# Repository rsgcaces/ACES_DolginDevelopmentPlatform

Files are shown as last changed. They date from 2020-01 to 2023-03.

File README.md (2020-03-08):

# RSGC ACES: Dolgin Development Platform (DDP)
 EAGLE and Fusion 360 Design files relating to the RSGC ACES Dolgin Development Platform

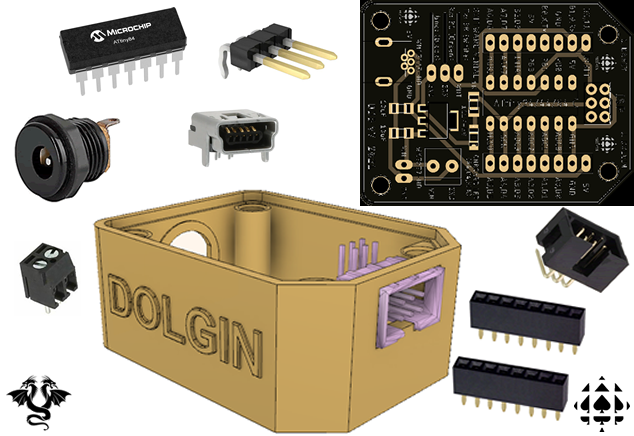
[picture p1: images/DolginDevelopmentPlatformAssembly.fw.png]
DDP Assembly


## USB to TTL Serial Support
Below is an image of the DDP software serial streaming the 2D readings of the thumb joystick to a Processing sketch that dynamically presents the circular trig functions.   
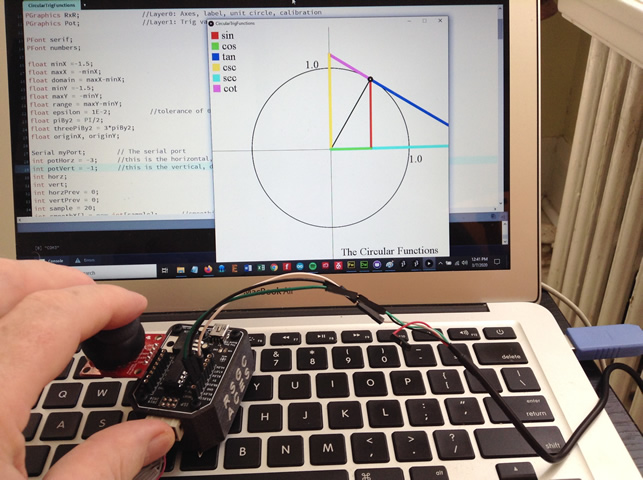
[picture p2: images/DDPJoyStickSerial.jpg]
Serial Support


## Morland Bargraph
The ATtiny84's pins were broken out with specific ACES' devices in mind. The image below shows the Morland Bargraph inserted strategically into the DDP.  
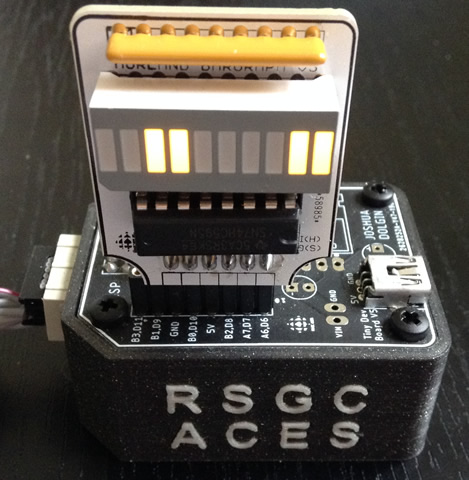
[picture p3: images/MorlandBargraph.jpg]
Morland Bargraph


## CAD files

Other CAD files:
AtTinyV26.f3d

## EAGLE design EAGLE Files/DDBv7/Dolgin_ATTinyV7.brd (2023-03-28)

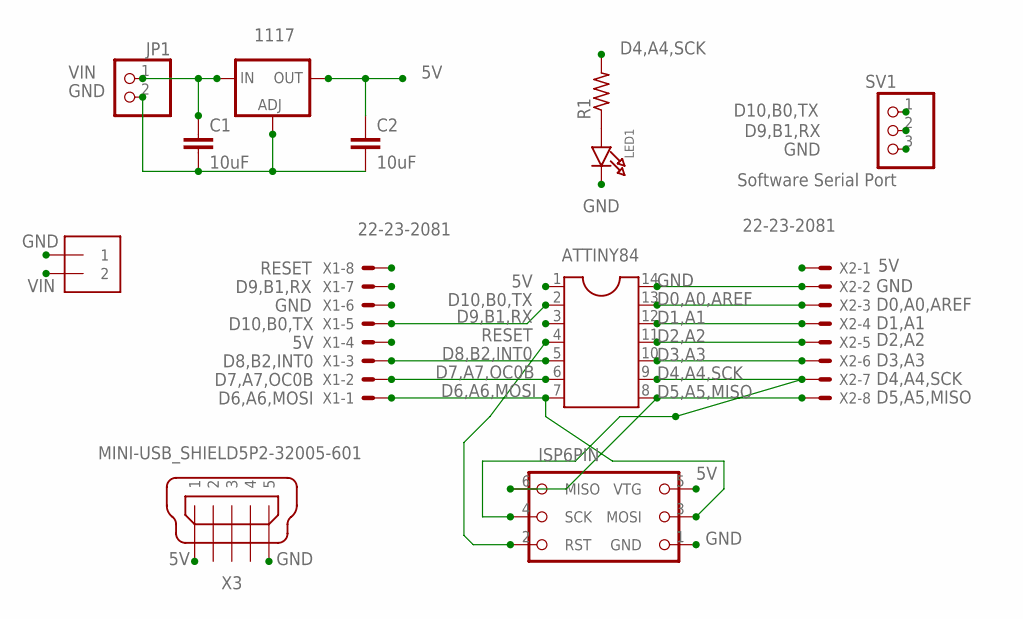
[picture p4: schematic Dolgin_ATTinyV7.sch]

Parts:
1117: LM1117SOT223-REFLOW; SOT223-R
ATTINY84: DIL14
C1, C2: 10uF; 1206
H1: ISP_HEADER; ICSP
J1: 1X2-3.5MM
JP1: PINHD-1X2; 1X02
LED1: LED1206; CHIPLED_1206
R1: R-US_R1206; R1206
SV1: Software Serial Port; 1X03/90
X1, X2: 22-23-2081
X3: MINI-USB_SHIELD5P2-32005-601; 32005-601

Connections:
5V: 1117.2 (OUT), ATTINY84.1, C2.1, H1.5 (VTG), X1.4, X2.1, X3.1
D0,A0,AREF: ATTINY84.13, X2.3
D1,A1: ATTINY84.12, X2.4
D2,A2: ATTINY84.11, X2.5
D3,A3: ATTINY84.10, X2.6
D4,A4,SCK: ATTINY84.9, H1.4 (SCK), R1.2, X2.7
D5,A5,MISO: ATTINY84.8, H1.6 (MISO), X2.8
D6,A6,MOSI: ATTINY84.7, H1.3 (MOSI), X1.1
D7,A7,OC0B: ATTINY84.6, X1.2
D8,B2,INT0: ATTINY84.5, X1.3
D9,B1,RX: ATTINY84.3, SV1.2, X1.7
D10,B0,TX: ATTINY84.2, SV1.3, X1.5
GND: 1117.1 (ADJ), ATTINY84.14, C1.2, C2.2, H1.1 (GND), J1.1, JP1.2, LED1.C, SV1.1, X1.6, X2.2, X3.5
unnamed: LED1.A, R1.1
RESET: ATTINY84.4, H1.2 (RST), X1.8
VIN: 1117.3 (IN), C1.1, J1.2, JP1.1

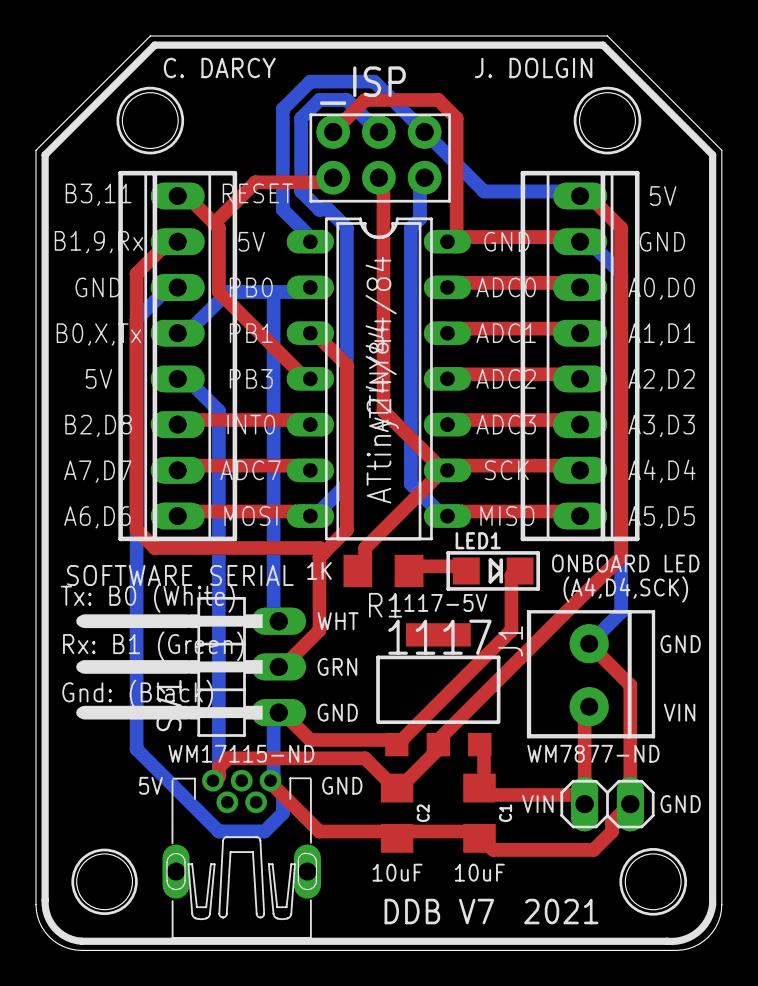
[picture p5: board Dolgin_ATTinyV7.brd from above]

Board: 2 copper layers, 38.1 x 50.8 mm, 17 parts (1 on the bottom side), 16 nets.

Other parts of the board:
U$1, U$2, U$4: ACES_LOGO_SMALL
U$3: MEDIUM_BSILK_TEXT

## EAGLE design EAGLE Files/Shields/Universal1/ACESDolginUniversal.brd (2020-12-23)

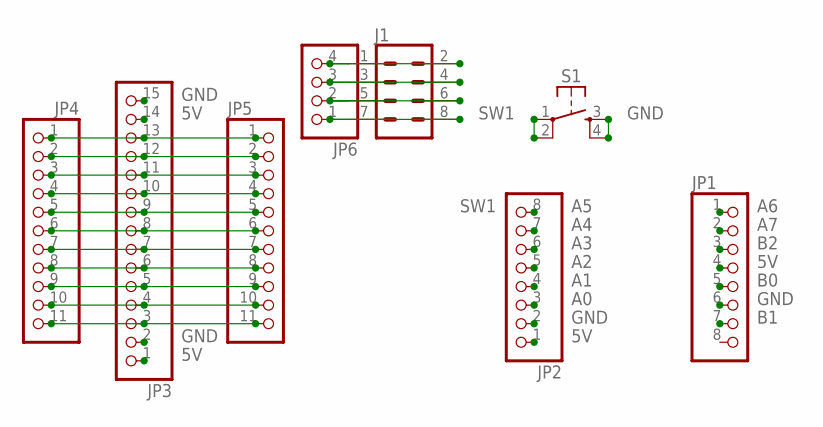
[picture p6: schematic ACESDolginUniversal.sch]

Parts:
J1: CONN_04X2; 2X4
JP1, JP2: PINHD-1X8; 1X08
JP3: PINHD-1X15; 1X15
JP4, JP5: PINHD-1X11; 1X11
JP6: PINHD-1X4; 1X04
S1: MOMENTARY_BUTTONS6MMSMALL; TACTILE_SWITCH_PTH_6.0MM

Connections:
5V: JP1.4, JP2.1, JP3.1, JP3.14
A0: JP2.3
A1: JP2.4
A2: JP2.5
A3: JP2.6
A4: JP2.7
A5: JP2.8
A6: JP1.1
A7: JP1.2
B0: JP1.5
B1: JP1.7
B2: JP1.3
GND: JP1.6, JP2.2, JP3.2, JP3.15, S1.3 (S), S1.4 (S1)
unnamed: J1.1, J1.2, JP6.4
unnamed: J1.3, J1.4, JP6.3
unnamed: J1.5, J1.6, JP6.2
unnamed: JP3.13, JP4.1, JP5.1
unnamed: JP3.12, JP4.2, JP5.2
unnamed: JP3.11, JP4.3, JP5.3
unnamed: JP3.10, JP4.4, JP5.4
unnamed: JP3.9, JP4.5, JP5.5
unnamed: JP3.8, JP4.6, JP5.6
unnamed: JP3.7, JP4.7, JP5.7
unnamed: JP3.6, JP4.8, JP5.8
unnamed: JP3.5, JP4.9, JP5.9
unnamed: JP3.4, JP4.10, JP5.10
unnamed: JP3.3, JP4.11, JP5.11
SW1: J1.7, J1.8, JP6.1, S1.1, S1.2 (P1)

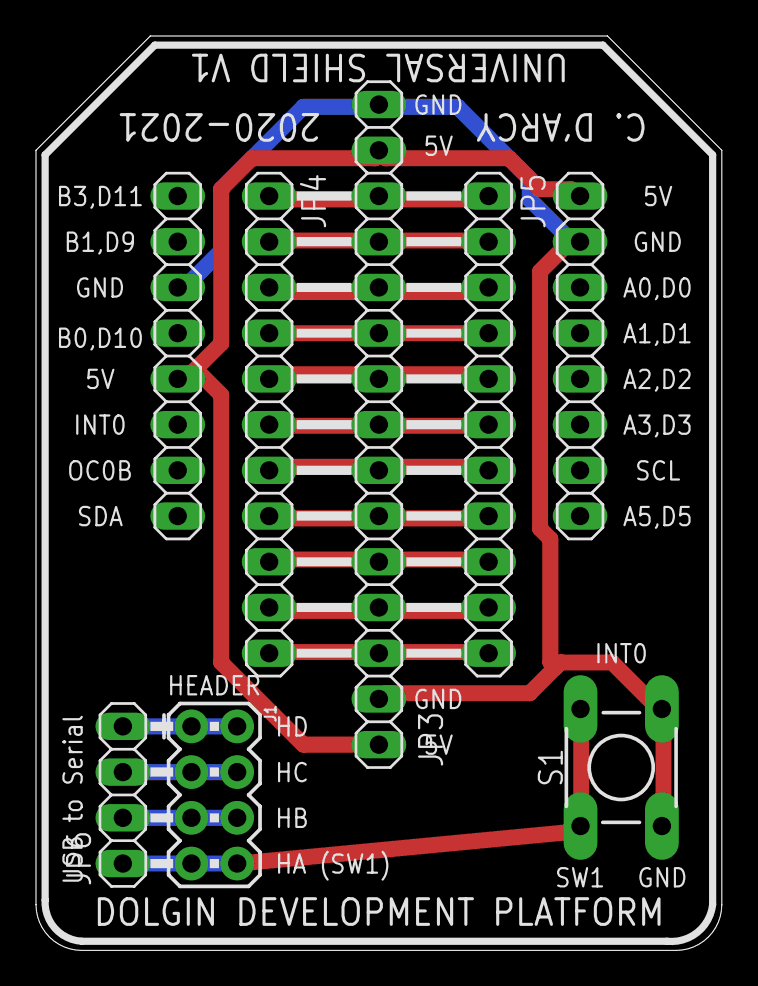
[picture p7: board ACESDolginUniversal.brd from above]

Board: 2 copper layers, 38.1 x 50.8 mm, 12 parts (0 on the bottom side), 17 nets.

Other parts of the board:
U$1: CAUTION_ELECTRIC
U$2, U$3: SMALL_TSILK_TEXT
U$5: MEDIUM_BSILK_TEXT

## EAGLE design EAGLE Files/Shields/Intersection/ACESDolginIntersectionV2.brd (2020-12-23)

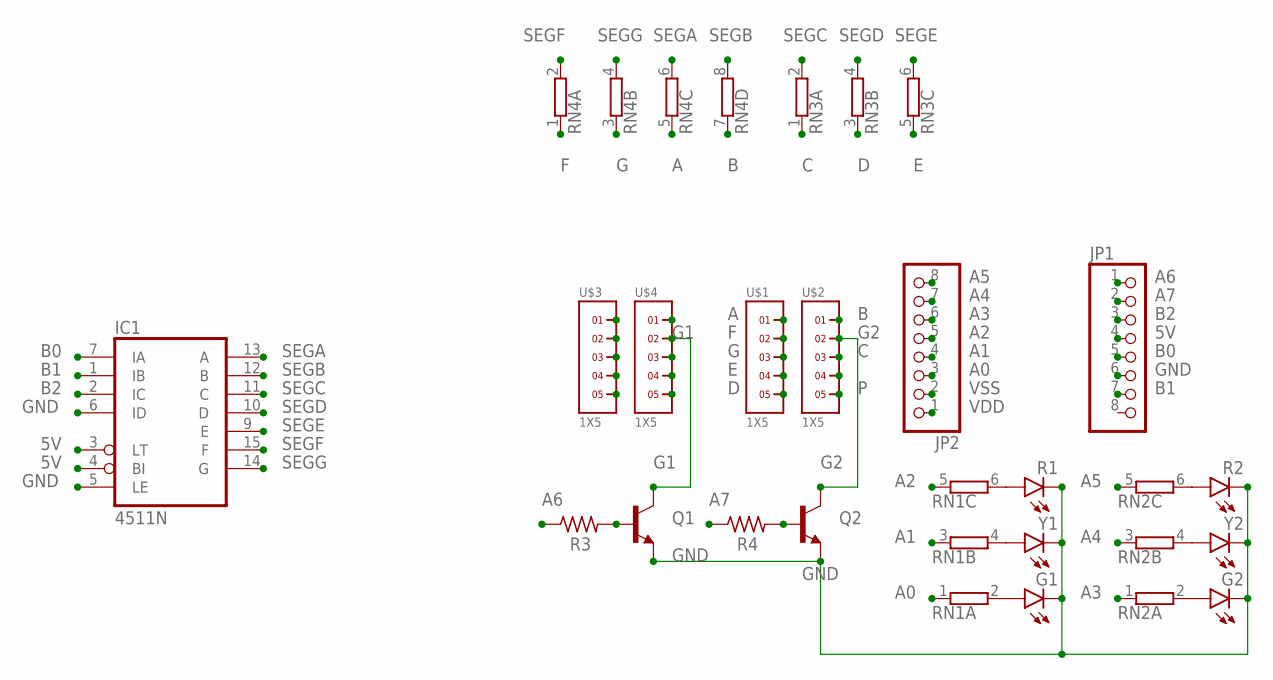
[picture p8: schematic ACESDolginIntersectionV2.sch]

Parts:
G1, G2: LED3MM
IC1: 4511N; DIL16
JP1, JP2: PINHD-1X8; 1X08
Q1, Q2: NPN2N3904; 2N3904
R1, R2: LED3MM
R3, R4: R-US_0207/10; 0207/10
RN1, RN2, RN3: E3R; SIL6
RN4: E4R; SIL8
U$1, U$2, U$3, U$4: 1X5
Y1, Y2: LED3MM

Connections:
5V: IC1.3 (LT), IC1.4 (BI), JP1.4
A: RN4.5 (1), U$1.1, U$3.1
A0: JP2.3, RN1.1
A1: JP2.4, RN1.3 (1)
A2: JP2.5, RN1.5 (1)
A3: JP2.6, RN2.1
A4: JP2.7, RN2.3 (1)
A5: JP2.8, RN2.5 (1)
A6: JP1.1, R3.1
A7: JP1.2, R4.1
B: RN4.7 (1), U$2.1, U$4.1
B0: IC1.7 (IA), JP1.5
B1: IC1.1 (IB), JP1.7
B2: IC1.2 (IC), JP1.3
C: RN3.1, U$2.3, U$4.3
D: RN3.3 (1), U$1.5, U$3.5
E: RN3.5 (1), U$1.4, U$3.4
F: RN4.1, U$1.2, U$3.2
G: RN4.3 (1), U$1.3, U$3.3
G1: Q1.C, U$4.2
G2: Q2.C, U$2.2
GND: G1.K (C), G2.K (C), IC1.5 (LE), IC1.6 (ID), JP1.6, Q1.E, Q2.E, R1.K (C), R2.K (C), U$2.4, U$4.4, Y1.K (C), Y2.K (C)
unnamed: G1.A, RN1.2
unnamed: RN1.4 (2), Y1.A
unnamed: R1.A, RN1.6 (2)
unnamed: G2.A, RN2.2
unnamed: RN2.4 (2), Y2.A
unnamed: R2.A, RN2.6 (2)
P: U$2.5, U$4.5
Q1BASE: Q1.B, R3.2
Q2BASE: Q2.B, R4.2
SEGA: IC1.13 (A), RN4.6 (2)
SEGB: IC1.12 (B), RN4.8 (2)
SEGC: IC1.11 (C), RN3.2
SEGD: IC1.10 (D), RN3.4 (2)
SEGE: IC1.9 (E), RN3.6 (2)
SEGF: IC1.15 (F), RN4.2
SEGG: IC1.14 (G), RN4.4 (2)
VDD: IC1.16 (VDD), JP2.1
VSS: IC1.8 (VSS), JP2.2

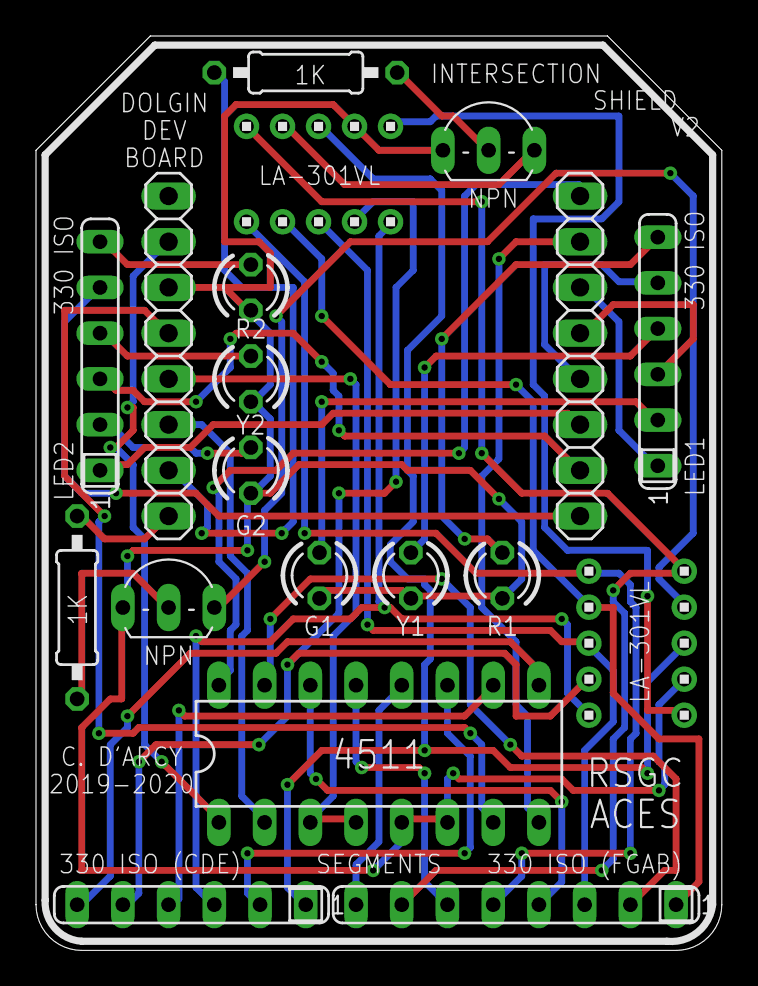
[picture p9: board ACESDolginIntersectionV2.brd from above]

Board: 2 copper layers, 38.1 x 50.8 mm, 22 parts (0 on the bottom side), 40 nets.

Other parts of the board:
U$5: ACES_LOGO_MEDIUM

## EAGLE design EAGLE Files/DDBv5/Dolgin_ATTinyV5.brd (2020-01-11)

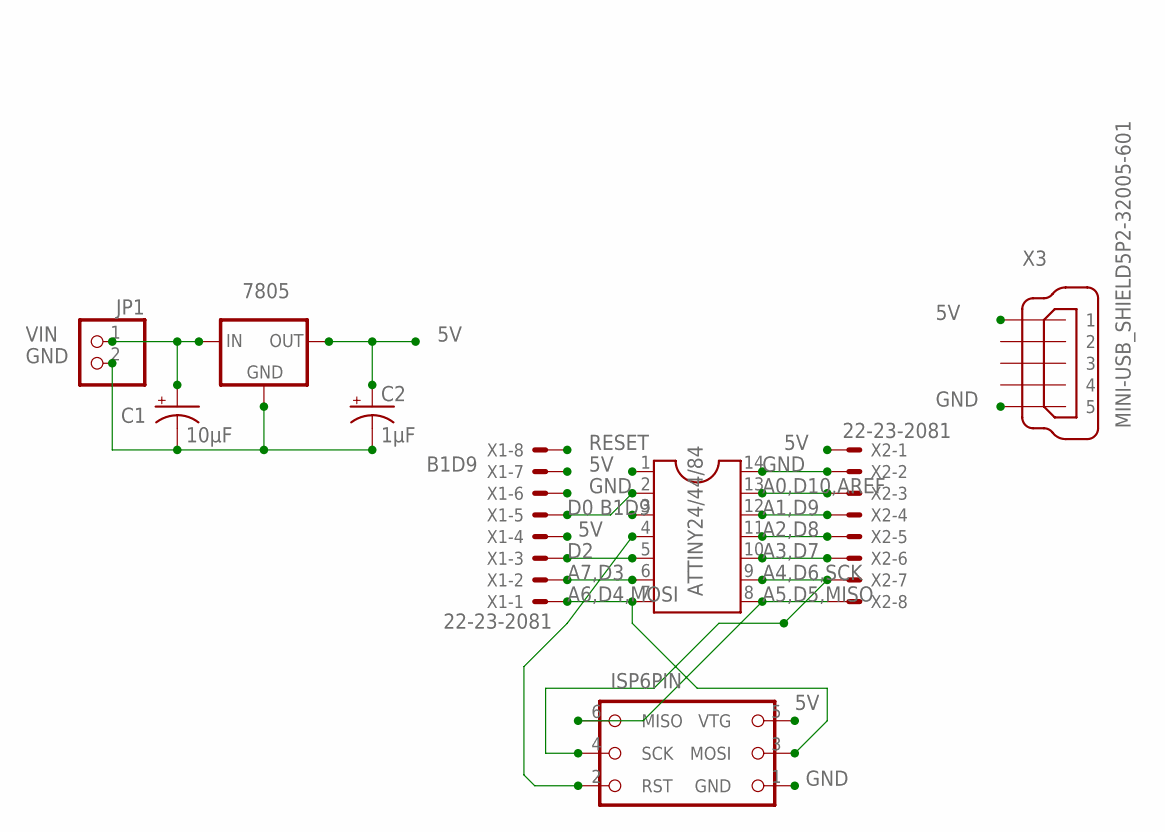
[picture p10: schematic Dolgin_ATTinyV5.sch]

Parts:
7805: LM78XX; 78XXL
ATTINY24/44/84: DIL14
C1: 10µF; CPOL-RADIAL-2.5MM-5MM
C2: 1µF; CPOL-RADIAL-2.5MM-5MM
H1: ISP_HEADER; ICSP
JP1: PINHD-1X2; 1X02
X1, X2: 22-23-2081
X3: MINI-USB_SHIELD5P2-32005-601; 32005-601

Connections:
5V: 7805.OUT, ATTINY24/44/84.1, C2.1 (+), H1.5 (VTG), X1.4, X2.1, X3.1
A0,D10,AREF: ATTINY24/44/84.13, X2.3
A1,D9: ATTINY24/44/84.12, X2.4
A2,D8: ATTINY24/44/84.11, X2.5
A3,D7: ATTINY24/44/84.10, X2.6
A4,D6,SCK: ATTINY24/44/84.9, H1.4 (SCK), X2.7
A5,D5,MISO: ATTINY24/44/84.8, H1.6 (MISO), X2.8
A6,D4,MOSI: ATTINY24/44/84.7, H1.3 (MOSI), X1.1
A7,D3: ATTINY24/44/84.6, X1.2
B1D9: ATTINY24/44/84.3, X1.7
D0: ATTINY24/44/84.2, X1.5
D2: ATTINY24/44/84.5, X1.3
GND: 7805.GND, ATTINY24/44/84.14, C1.2 (-), C2.2 (-), H1.1 (GND), JP1.2, X1.6, X2.2, X3.5
RESET: ATTINY24/44/84.4, H1.2 (RST), X1.8
VIN: 7805.IN, C1.1 (+), JP1.1

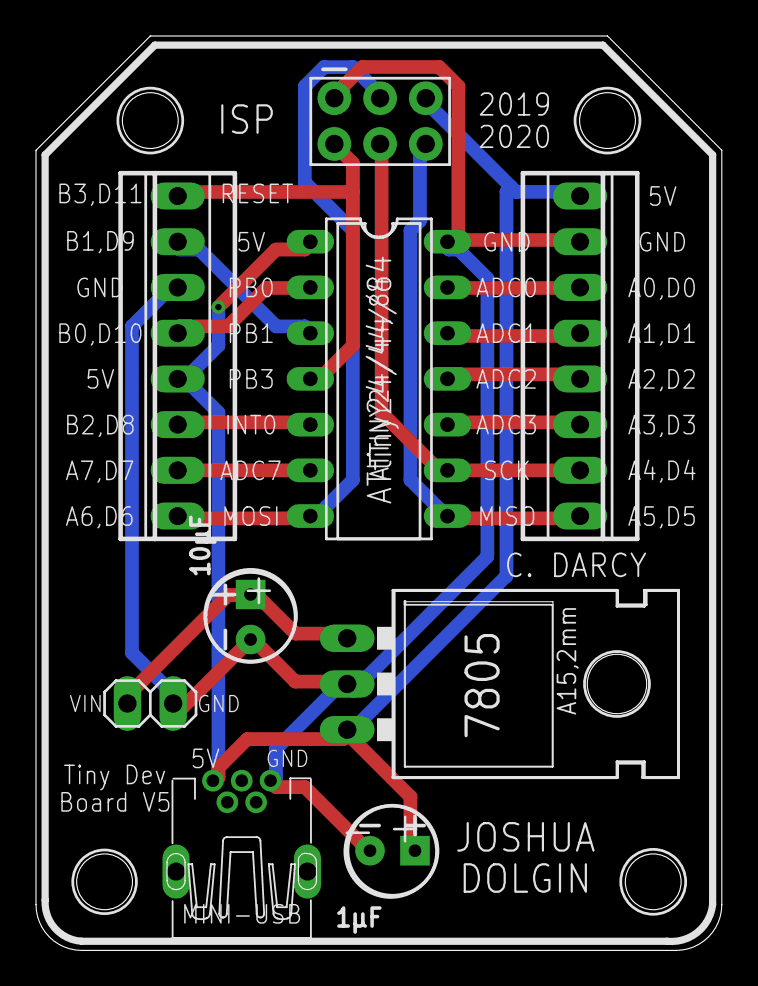
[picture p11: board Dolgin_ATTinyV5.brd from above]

Board: 2 copper layers, 38.1 x 50.8 mm, 10 parts (1 on the bottom side), 15 nets.

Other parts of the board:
U$1: ACES_LOGO_SMALL

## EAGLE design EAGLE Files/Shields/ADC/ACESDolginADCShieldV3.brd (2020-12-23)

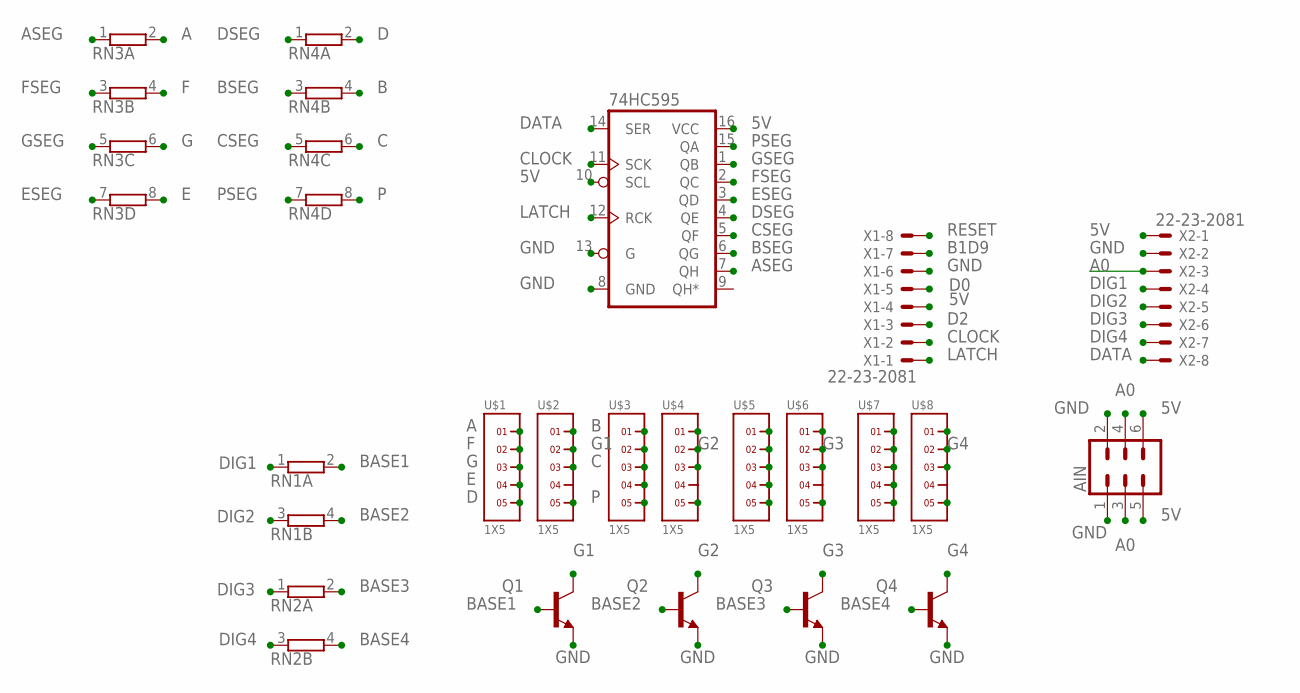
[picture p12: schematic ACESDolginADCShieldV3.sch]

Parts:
74HC595: 595; DIL16
AIN: CONN_03X2FEMALE; 2X3
Q1, Q2, Q3, Q4: NPN2N3904; 2N3904
RN1, RN2: E2R; SIL4
RN3, RN4: E4R; SIL8
U$1, U$2, U$3, U$4, U$5, U$6, U$7, U$8: 1X5
X1, X2: 22-23-2081

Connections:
5V: 74HC595.10 (SCL), 74HC595.16 (VCC), AIN.5, AIN.6, X1.4, X2.1
A: RN3.2, U$1.1, U$3.1, U$5.1, U$7.1
A0: AIN.3, AIN.4, X2.3
ASEG: 74HC595.7 (QH), RN3.1
B: RN4.4 (2), U$2.1, U$4.1, U$6.1, U$8.1
B1D9: X1.7
BASE1: Q1.B, RN1.2
BASE2: Q2.B, RN1.4 (2)
BASE3: Q3.B, RN2.2
BASE4: Q4.B, RN2.4 (2)
BSEG: 74HC595.6 (QG), RN4.3 (1)
C: RN4.6 (2), U$2.3, U$4.3, U$6.3, U$8.3
CLOCK: 74HC595.11 (SCK), X1.2
CSEG: 74HC595.5 (QF), RN4.5 (1)
D: RN4.2, U$1.5, U$3.5, U$5.5, U$7.5
D0: X1.5
D2: X1.3
DATA: 74HC595.14 (SER), X2.8
DIG1: RN1.1, X2.4
DIG2: RN1.3 (1), X2.5
DIG3: RN2.1, X2.6
DIG4: RN2.3 (1), X2.7
DSEG: 74HC595.4 (QE), RN4.1
E: RN3.8 (2), U$1.4, U$3.4, U$5.4, U$7.4
ESEG: 74HC595.3 (QD), RN3.7 (1)
F: RN3.4 (2), U$1.2, U$3.2, U$5.2, U$7.2
FSEG: 74HC595.2 (QC), RN3.3 (1)
G: RN3.6 (2), U$1.3, U$3.3, U$5.3, U$7.3
G1: Q1.C, U$2.2
G2: Q2.C, U$4.2
G3: Q3.C, U$6.2
G4: Q4.C, U$8.2
GND: 74HC595.8 (GND), 74HC595.13 (G), AIN.1, AIN.2, Q1.E, Q2.E, Q3.E, Q4.E, X1.6, X2.2
GSEG: 74HC595.1 (QB), RN3.5 (1)
LATCH: 74HC595.12 (RCK), X1.1
P: RN4.8 (2), U$2.5, U$4.5, U$6.5, U$8.5
PSEG: 74HC595.15 (QA), RN4.7 (1)
RESET: X1.8

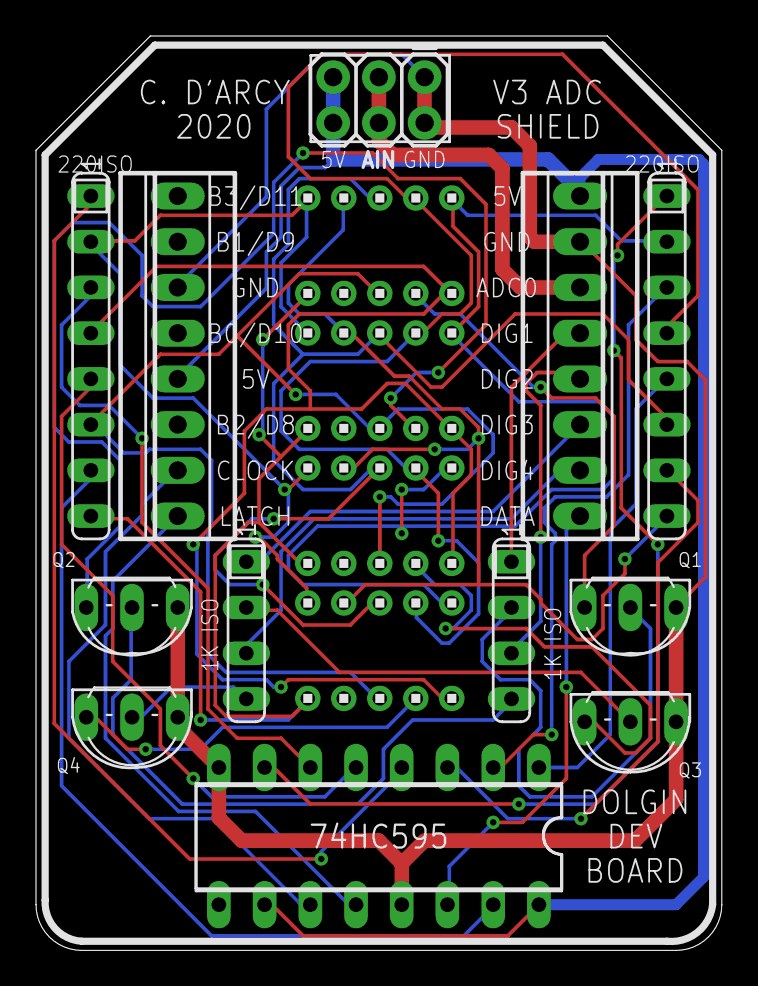
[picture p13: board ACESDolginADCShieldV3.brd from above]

Board: 2 copper layers, 38.1 x 50.8 mm, 21 parts (0 on the bottom side), 34 nets.

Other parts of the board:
U$9: ACES_LOGO_MEDIUM

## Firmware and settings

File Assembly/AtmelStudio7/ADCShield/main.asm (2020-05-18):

;PROJECT    :ADCShieldASM
;PURPOSE    :Demonstration of cumulative use cases: functions, Stack, binary to BCD  
;AUTHOR     :C. D'Arcy
;DATE       :2020 05 20
;DEVICE     :Dolgin Development Platform
;MCU        :ATtiny84
;COURSE     :ICS4U
;STATUS     :Not Working
;REFERENCE  :https://mail.rsgc.on.ca/~cdarcy/Datasheets/doc0856.pdf
.include	"prescalers84.h"    ;include all possible Timer/Counter prescaler defines
.def    util		= r16       ;readability is enhanced through 'use' aliases for GP Registers
.def	base		= r17		;register holds base pin of active transistor
.def	bin0		= r18		;low byte of 16-bit ADC reading
.def	bin1		= r19       ;high byte of 16-bit ADC reading
.def	BCD10		= r22		;two lowest BCD digits of the Double-Dabble
.def	BCD32		= r23       ;next two BCD digits of the Double Dabble
.def	BCD4		= r24       ;highest BCD digit of the Double DAbble (always 0 for 10-bit ADC)
.equ	DDR			= DDRA      ;typically, we'll need the use of PortA
.equ	PORT		= PORTA     ;both its data direction register and output register and, eventually,
.equ    units		= PA4		;ground the respective displays 
.equ    DATA		= PA5       ;595 data pin
.equ    LATCH		= PA6       ;595 latch pin
.equ    CLOCK		= PA7       ;595 clock pin
.cseg                           ;locate for Code Segment (FLASH) 
; ***** INTERRUPT VECTOR TABLE ***********************************************
.org    0x0000                  ;start of Interrupt Vector Table (IVT) aka. Jump Table
		rjmp	reset			;lowest interrupt address == highest priority!
;.org	OVF1addr				;Local Timer 1 Overflow ISR used but not explicitly required
;		rjmp	TIM1_OVF		;as sole purpose is to trigger the next ADC Conversion
.org	ADCCaddr				;Analog to Digital Conversion Complete vector
		rjmp	ADC_Conv_Comp	;ISR: ADC Complete ISR
; ***** FLASH DATA ***********************************************************
.org	INT_VECTORS_SIZE        ;position segment LUT beyond the IVT
segStart:						;(MSBFIRST:)ABCDEFGx
.db		0b11111100,0b01100000,0b11011010,0b11110010  ;0-3
.db		0b01100110,0b10110110,0b10111110,0b11100000  ;4-7
.db		0b11111110,0b11110110,0b11101110,0b00111110  ;8-b
.db		0b10011100,0b01111010,0b10011110,0b10110110  ;C-F
segEnd:
; ***** START OF CODE ********************************************************
.org	0x0100              ;well clear of IVT
reset:                          ;PC jumps to here (start of code) on reset interrupt...	ldi		util,low(RAMEND)    ;position the Stack pointer to the end of SRAM
	ldi		util,low(RAMEND)	;ensure the Stack Pointer points to the end
	out		SPL,util            ;of SRAM to ensure maximum stack size
	ldi		util,high(RAMEND)   ;This is technically not necessary as the  
	out		SPH,util            ;assembler does it for us, but it's good practice
	ldi		util,0xFE			;easy to forget to set output ports
	out		DDR,util			;this has cost me more than a few lost hours :(

	rcall	ADCSetup			;configure Timer 1 Overflow interrupt to trigger conversions
	rcall	Timer1Setup         ;Normal mode to generate a 1Hz interrupt
	sei							;enable global interrupt system
	rcall	packedBCDPoV		;call function and remain, forever
 hold:
	rjmp	hold				;watch Shield display while adjusting pot or other V.D. 

Timer1Setup:
	clr		util				;zero everything for the most basic use
	out		TCCR1A,util			;set for Timer/Counter1 Mode 0 (Normal)
	ldi		util,T1ps64			;Clk/64 yields 1Hz (approximately)
 	out		TCCR1B,util			;do it
	clr		util				;not technically necessary, but jworth a look... 
	out		TCNT1H,util			;zero the high byte of the counter first
	out		TCNT1L,util			;zero the low byte of the counter second
	ldi		util,1<<TOIE1		;prepare to enable Timer 1 Overlow Interrupt capability
	out		TIMSK1,util			;do it
	ret

;ISR:
;TIM1_OVF:
;	reti						;not explicitly required, see IVT Comment above

ADCSetup:
	ldi		util, 0						;AVcc as reference, MUX:A0
	out		ADMUX,util					;
;Enable, Start Dummy Conversion, prescaler of 64 to yield freq of 128k
	ldi		util,(1<<ADEN)|(1<<ADSC)|(1<<ADPS2)|(1<<ADPS1)	;
	out		ADCSRA,util					;
dummy:
	in		util,ADCSRA					;read the ADCSRA 
	sbrs	util,ADIF					;is the 25 cycle conversion complete?
	rjmp	dummy						;if not, keep waiting
	sbi		ADCSRA,ADIF					;dummy conversion complete, clear the interrupt flag (by setting it!)
	sbi		ADCSRA,ADATE				;enable auto-triggering
	ldi		util,(1<<ADTS2)|(1<<ADTS1)	;request Timer 1 Overflow as Trigger Source
	out		ADCSRB,util					;set Trigger
	sbi		ADCSRA,ADIE					;enable ADC interrupt
	ret									;off we go...

;ISR:
ADC_Conv_Comp:
	in		bin0,ADCL					;MUST read the low-byte of the conversion,
	in		bin1,ADCH					;then read the high byte of the conversion
	rcall	bin16BCD5					;routine convert 16-bit binary to 5 (packed) byte BCD
	reti								;return to PoVing with new value...

;****** DOUBLE DABBLE Algorithm applied to 16-bit decimal *************************
;PreConditions
; 16-bit binary number to be converted is in register pair bin1:bin0 = r19:r18
;Clobbers: R24:r23:r22
;PostConditions: packedBCD in register set BCD4:BCD32:BCD10=R24:r23:r22
;**********************************************************************************
bin16BCD5:
	push	r16                 ;preserve contents of registers to be utilized
	push	r17                 ;
	push	r20					;
	push	r21					;
	
	ldi		r20,0x03            ;prepare the constant 3 in two ways for efficiency
	ldi		r21,0x30            ;one as a low nibble add and the other as a high nibble add
	ldi		r17,16              ;Loop Control Variable (LCV): a full 16 shifts are required
	
	clr		r24                 ;ensure the BCD target registers are zeroed
	clr		r23                 ;"
	clr		r22                 ;"
binNext:
	lsl		r18                 ;Shift bin0 left, MSB -> C Flag of SREG
	rol		r19                 ;rotate bin1 left so C Flag becomes LSB
	rol		r22                 ;rotate similarly for BCD10
	rol		r23                 ;rotate similarly for BCD32
	rol		r24                 ;rotate similarly for BCD4
	dec		r17                 ;one less shift to do...
	breq	binDone             ;are we finished all 16?
bin1s:
	mov		r16,r22             ;prepare to check BCD10 for need to Add 3
	andi	r16,0x0F            ;temporarily mask off high nibble
	cpi		r16,0x05            ;is the result greater than 4?
	brlo	bin10s              ;if not, continue
	add		r22,r20             ;if so, Add 3
bin10s:
	cpi		r22,0x50            ;is the high nibble of BCD10 greater than 4?
	brlo	bin100s             ;if not, continue
	add		r22,r21             ;if so, Add 3 to high nibble of BCD10
bin100s:
	mov		r16,r23             ;prepare to check BCD32 for need to Add 3
	andi	r16,0x0F            ;temporarily mask off high nibble
	cpi		r16,0x05            ;is the result greater than 4?
	brlo	bin1000s            ;if not, continue
	add		r23,r20             ;if so, Add 3
bin1000s:
	cpi		r23,0x50            ;is the high nibble of BCD32 greater than 4?
	brlo	bin10000s           ;if not, continue
	add		r23,r21             ;if so, Add 3 to high nibble of BCD32
bin10000s:                      ;not necessarily for ADC values, but complete for future use                     
	mov		r16,r24             ;prepare to check BCD4 for need to Add 3
	cpi		r16,0x05            ;is the result greater than 4?
	brlo	binNext             ;if not, continue
	add		r24,r20             ;if so, Add 3
	rjmp	binNext             ;keep going...
binDone:                        
	pop		r21                 ;restore preserved register values
	pop		r20                 ;"
	pop		r17                 ;"
	pop		r16                 ;"
	ret

;************PACKEDBCDPOV*************************************
;PreConditions...
; packed BCD value as follows: BCD32:BCD10 = R23:r22
;Predefines: PORT, digital pin for units is defined
;PostConditions: packed BCD value persistent on the ADC displays
;************************************************************* 
packedBCDPoV:
;Stack use is not really required
; as function never exits (only interrupted) 
 push	r16                     ;util
 push	r17                     ;base 
 push	r18                     ;(bin0)
 push	r19                     ;(bin1)

 ldi	base,1<<units           ;to get the loop started correctly assume units have been done
 sbi	PORT,units              ;this requires setting the units' base pin in the PORT
 ldi	XL,low(segStart<<1)		;one time initialization of pointer to 
 ldi	XH,high(segStart<<1)	; starting address of LUT

PoVTop:							;display order: thousands>hundreds>tens>units
 mov	r16,r23                 ;obtain BCD32
 swap	r16                     ;switch nibbles
 andi	r16,0x0F                ;obtain the thousands digit
 movw	Z,X                     ;assign X to Z; the start of the segment LUT
 add	ZL,r16                  ;use digit for correct offset into the segment LUT 
 lpm	r20,Z                   ;get the segment map corresponding to the thousands digit
 rcall	updateDisplay           ;self-explanatory
 rcall	delay5ms                ;timeout to reduce flicker

 mov	r16,r23                 ;obtain BCD32
 andi	r16,0x0F                ;obtain the hundreds digit
 movw	Z,X                     ;assign X to Z; the start of the segment LUT
 add	ZL,r16                  ;use digit for correct offset into the segment LUT 
 lpm	r20,Z                   ;get the segment map corresponding to the thousands digit
 rcall	updateDisplay           ;self-explanatory
 rcall	delay5ms                ;timeout to reduce flicker
 
 mov	r16,r22                 ;obtain BCD10
 swap	r16                     ;switch nibbles
 andi	r16,0x0F                ;obtain the tens digit
 movw	Z,X                     ;assign X to Z; the start of the segment LUT
 add	ZL,r16                  ;use digit for correct offset into the segment LUT 
 lpm	r20,Z                   ;get the segment map corresponding to the thousands digit
 rcall	updateDisplay           ;self-explanatory
 rcall	delay5ms                ;timeout to reduce flicker

 mov	r16,r22                 ;obtain BCD10
 andi	r16,0x0F                ;obtain the units digit
 movw	Z,X                     ;assign X to Z; the start of the segment LUT
 add	ZL,r16                  ;use digit for correct offset into the segment LUT 
 lpm	r20,Z                   ;get the segment map corresponding to the thousands digit
 rcall	updateDisplay           ;self-explanatory
 rcall	delay5ms                ;timeout to reduce flicker

 rjmp	PoVTop                  ;repeat unconditionally

 pop	r19                     ;Unreachable as function never exits but,
 pop	r18                     ; for the record, if use to be exported
 pop	r17                     ;
 pop	r16                     ;
 ret

;************UPDATEDISPLAY*************************************
;PreConditions...
; PORTA bits declared for output
; X points to start of Segment LUT in Flash
; packed BCD value as follows: BCD32:BCD10 = R23:r22
;Predefines: PORT, units
;PostConditions: packed BCD value persistent on the ADC displays
;************************************************************* 
updateDisplay:
;----Toggle previous base pin so it is OFF------------------------------------------
 in		r16,PORT                ;read the PORT for the current base pin
 eor	r16,base				;toggle previous base pin off
 out	PORT,r16                ;write the PORT 
;----End of toggle OFF ----------------------------------------------------
 rcall	shiftout				;shift out the segment map (it's in n!)
;----Determine which base pin to turn ON------------------------------------------
 sbrc	base,units				;have we already reached the units digit? 
 ldi	base,1<<PA0				;if so, we're here and we need to prepare for the thousands digit (PA1) 
 lsl	base					;shift the base pin to turn on the next digits
;----Toggle correct base pin so it is ON------------------------------------------
 in		r16,PORT                ;read the PORT
 eor	r16,base				;toggle previous base pin off
 out	PORT,r16                ;write the PORT
;-------End of toggle base pin so it is ON ---------------------------------------------------
 ret

;************SHIFTOUT ********************************************************
;PreConditions:
; byte to be shifted is in r20
; X points to start of Segment LUT in Flash
; shift order is MSBFIRST
;Predefines: PORT, LATCH, CLOCK, DATA
;PostConditions: Segments for BCD byte in r20 appear on the respective display
;*****************************************************************************
shiftout:                       ;shifts r20 into the 595 MSBFIRST
 push	r16						;(util)
 push	r18						;(bin0)

 ldi	r18,0x80                ;commit to MSBFIRST
 cbi	PORT,LATCH              ;pull LATCH pin LOW

topSO:
 cbi	PORT,CLOCK              ;pull CLOCK pin LOW
 mov	r16,r20                 ;obtain a copy of the original value to be presented 
 and	r16,r18                 ;mask off the target bit
 breq	lo                      ;was it 0?
 sbi	PORT,DATA               ;no, so pull DATA pin HIGH
 rjmp	clockit                 ;ready to clock the 1
lo:
 cbi	PORT,DATA               ;else, it was a 0, so pull DATA pin LOW
clockit:
 sbi	PORT,CLOCK              ;pull CLOCK pin HIGH
 lsr	r18                     ;MSBFIRST shifts the mask right
 brne	topSO                   ;repeat if there are still more bits to stuff in

 sbi	PORT,LATCH              ;pull LATCH pin HIGH to present 595's internal latches on output pins
 
 pop	r18						;util
 pop	r16						;mask
 ret                            ;finished, return.

delay5ms:
; Assembly code auto-generated
; by utility from Bret Mulvey
; Delay 40 000 cycles
; 5ms at 8.0 MHz
 push	r21                     ;preserve exploited register values
 push	r25                     ;
 ldi	r21, 52                 ;
 ldi	r25, 242                ;
L1:
 dec	r25                     ;
 brne	L1                      ;
 dec	r21                     ;
 brne	L1                      ;
 nop
 pop	r25                     ;restore preserved register values 
 pop	r21                     ;
 ret 

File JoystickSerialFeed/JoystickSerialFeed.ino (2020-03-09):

// PROJECT  :JoystickSerialFeed
// PURPOSE  :High-level reading and Serial println of two ThumbJoystick pots
//          :Support for Processing Circular Functions Demo
// COURSE   :ICS3U/ICS4U
// AUTHOR   :C. D'Arcy
// DATE     :Latest: 2020 03 07
// MCU      :DDP(84)/(UNO)328P
// STATUS   :Working
// REFERENCE:https://www.instructables.com/id/ATtiny8485-In-circuit-Debugging-Using-Serial-Outpu/
// NOTES    :DDP: (0,1,2,3,4)=(VCC,VERT,HORZ,SEL,GROUND)
//          :This would be ideal for the Universal Shield (Challenge???!!)
//Activate one of the two targets...
//#define   LOCAL           //Serial Monitor or Plotter
#define   PROCESSING        //...Arduino/MyProcessing/JoyStickTrig/CircularTrigFunctions.pde

// Pick an MCU...
#if defined (__AVR_ATtiny84__)
#define VCC     0
#define VERT    1         //ADC1
#define HORZ    2         //ADC2
#define SEL     3         //
#define GND     4         //  
#define HORZOUT 6         //PWM: OC1A (Pin 5:OC1B inaccessbile)
#define VERTOUT 8         //PWM: OC0A (avoided pin 7:OC0B)
#define RXPIN   9         // Pin used for Serial receive
#define TXPIN   10        // Pin used for Serial transmit
#define VERTGND 10        //
#include <SoftwareSerial.h>    // Arduino SoftwareSerial class
SoftwareSerial mySerial(RXPIN, TXPIN);
#else  //#if defined(__AVR_ATmega328P__)
#define VCC     14        //A0
#define VERT    15        //ADC1
#define HORZ    16        //ADC2
#define SEL     17        //ADC3
#define GND     18        //ADC4  
#define HORZOUT 11        //PWM: OC2A (Pin 11)
#define VERTOUT 9         //PWM: OC1A (Pin 9)
#define VERTGND 8         //
#endif
#define LOWER 0
#define UPPER 255

uint8_t horzRead, vertRead;

void setup() {
#if defined (__AVR_ATmega328P__)
  Serial.begin(9600);
  //   Serial.println(String(0)+" "+String(260));
  //   Serial.print(" ");
  //   Serial.println(255);
#endif
#if defined (__AVR_ATtiny84__)
  pinMode(VCC, OUTPUT);       //provides 5V (little current draw)
  digitalWrite(VCC, HIGH);    //
  pinMode(GND, OUTPUT);       //provides sink, again, little draw
  digitalWrite(GND, LOW);
  mySerial.begin(9600);       // Start serial processing
  delay(1000);                // Give Serial class time to complete initialization.
  // otherwise, 1st output likely missing or garbled
  //  mySerial.println("SETUP Complete - SoftwareSerial Example");
  //  pinMode(VERTGND, OUTPUT);   //provide a pseudo-ground for LED sourced
  //  digitalWrite(VERTGND, LOW); //by PWM (OC0A) on pin 8
#endif
}

void loop() {
  // Avoid 0, used as the registration marker
  horzRead = constrain(analogRead(HORZ) >> 2, 1, 255);
  delay(10);
  vertRead = constrain(analogRead(VERT) >> 2, 1, 255);
  delay(10);
  //  analogWrite(HORZOUT, horzRead);
  //  analogWrite(VERTOUT, vertRead);
#if defined (__AVR_ATmega328P__)
#ifdef PROCESSING
  Serial.write(0);            //registration marker
  Serial.write(horzRead);     //
  Serial.write(vertRead);     //place the byte value in the stream
#else  //LOCAL Serial Monitor/Plotter...
//  Serial.print(LOWER + String(" "));
//  Serial.print(UPPER + String(" "));
  Serial.print(horzRead + String(" "));
  Serial.println(vertRead);
#endif
#endif
#if defined (__AVR_ATtiny84__)
#ifdef PROCESSING
  mySerial.write((byte)0);      //registration marker
  mySerial.write((byte)horzRead);     //
  mySerial.write((byte)vertRead);     //place the byte value in the stream
#else  //LOCAL Serial Monitor/Plotter...
  //   mySerial.print(LOWER + String(" "));
  //   mySerial.print(UPPER + String(" "));
  mySerial.print(horzRead + String(" "));
  mySerial.println(vertRead);
#endif
#endif
}

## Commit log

2020-01-11 2020 01 11
    [Dolgin_ATTinyV5.brd, Dolgin_ATTinyV5.sch]
2020-01-13 Added: 2020 01 13
    [AtTinyV26.f3d]
2020-03-07 Added: 2020 03 07
    Serial support for DDP to the Arduino Serial Monitor and Plotter. Uses the Software Serial library for use with Adafruit's USB-to-Serial Cable (#954).
2020-03-09 Updated: 2020 03 09
    Example of SoftwareSerial library I/O with the DDP through the use of Adafruit's USB-to-TTL Serial Cable (#954).
2020-05-18 2020 05 18
    Pure assembly version of ADC Shield reading pot or other VD, applying the Double Dabble coversion to BCD and PoVing te result to the displays. Uses Timer 1 OVerflow (1 Hz) as the trigger source
2020-05-18 2020 05 18
    Basic example of Timer 0 Overflow toggles an LED on the DDP at 32 Hz.
2020-05-18 2020 05 18
    Basic example of Timer 1 Overlfow (Normal Mode 0) used to toggle an LED on DDP digital pin 0 at 1Hz.
2020-05-18 uploded 2020 05 18
    Use of External Interrupt on the DDP using the PB on the Universal Shield. wired to INT0 (PB2).
2020-05-21 2020 05 22
    AVR Assembly control of a servo's horn position using the ATtiny84's Timer/Counter0 Fast PWM Mode 7. Video support:
    https://www.youtube.com/watch?v=lg2KNSboOUQ&feature=youtu.be
2020-12-23 Folder Restructuring
    [ACESDolginADCShieldV3.brd, ACESDolginADCShieldV3.sch, ACESDolginIntersectionV2.brd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]
2023-03-28 2023 03 29
    [Dolgin_ATTinyV7.brd, Dolgin_ATTinyV7.sch]

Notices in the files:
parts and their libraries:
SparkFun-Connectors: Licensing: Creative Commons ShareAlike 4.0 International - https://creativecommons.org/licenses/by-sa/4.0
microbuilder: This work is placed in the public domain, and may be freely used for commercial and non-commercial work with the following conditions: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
